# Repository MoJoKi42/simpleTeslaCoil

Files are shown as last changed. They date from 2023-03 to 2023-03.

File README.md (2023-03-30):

# simpleTeslaCoil
just a simple TeslaCoil (SSTC) with basic components

<ins>Few facts:</ins>
- 12-24V input voltage
- around 3-4A current maximum
- up to 550kHz frequency possible
- 100x100mm board

Picture of the finished board:
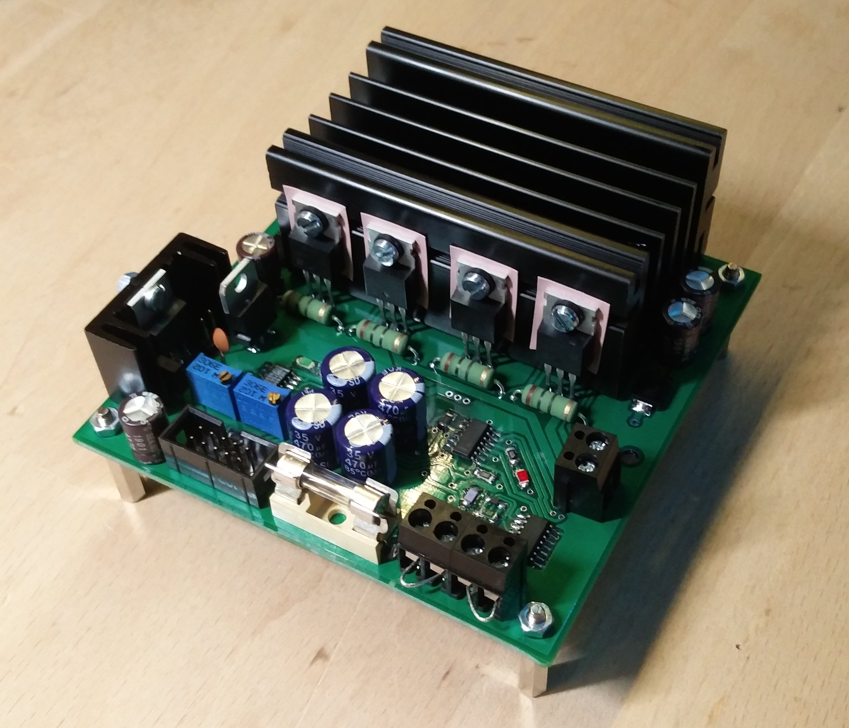
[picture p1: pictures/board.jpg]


And a picture of my final construction with coil and PSU:
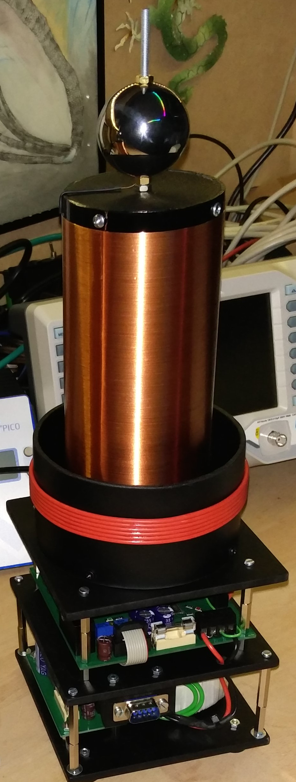
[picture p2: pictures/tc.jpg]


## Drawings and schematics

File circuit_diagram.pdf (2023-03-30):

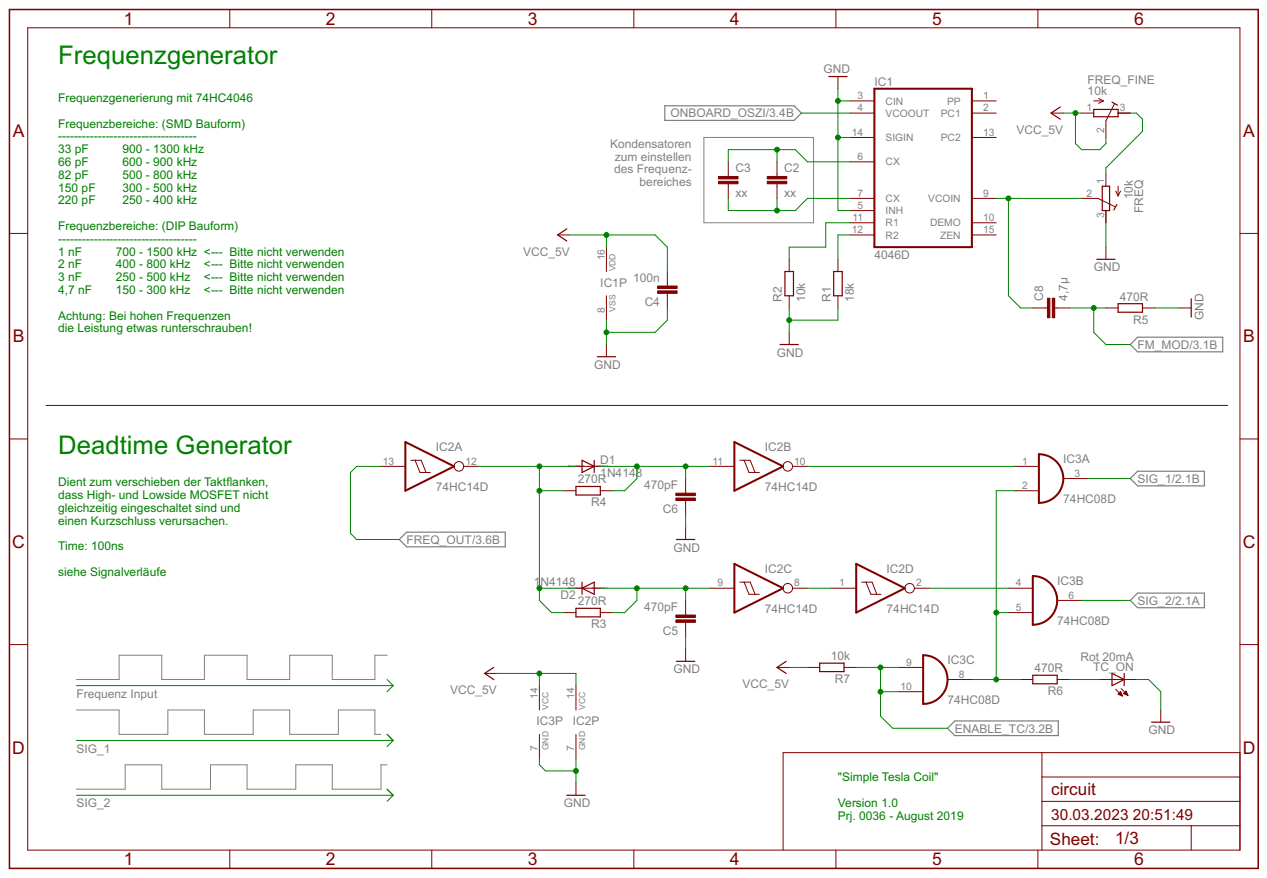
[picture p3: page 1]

die Leistung etwas runterschrauben!

Dient zum verschieben der Taktflanken, dass High- und Lowside MOSFET nicht

gleichzeitig eingeschaltet sind und
einen Kurzschluss verursachen. Time: 100ns

"Simple Tesla Coil" Version 1.0 Prj. 0036 - August 2019

Sheet: 1/3

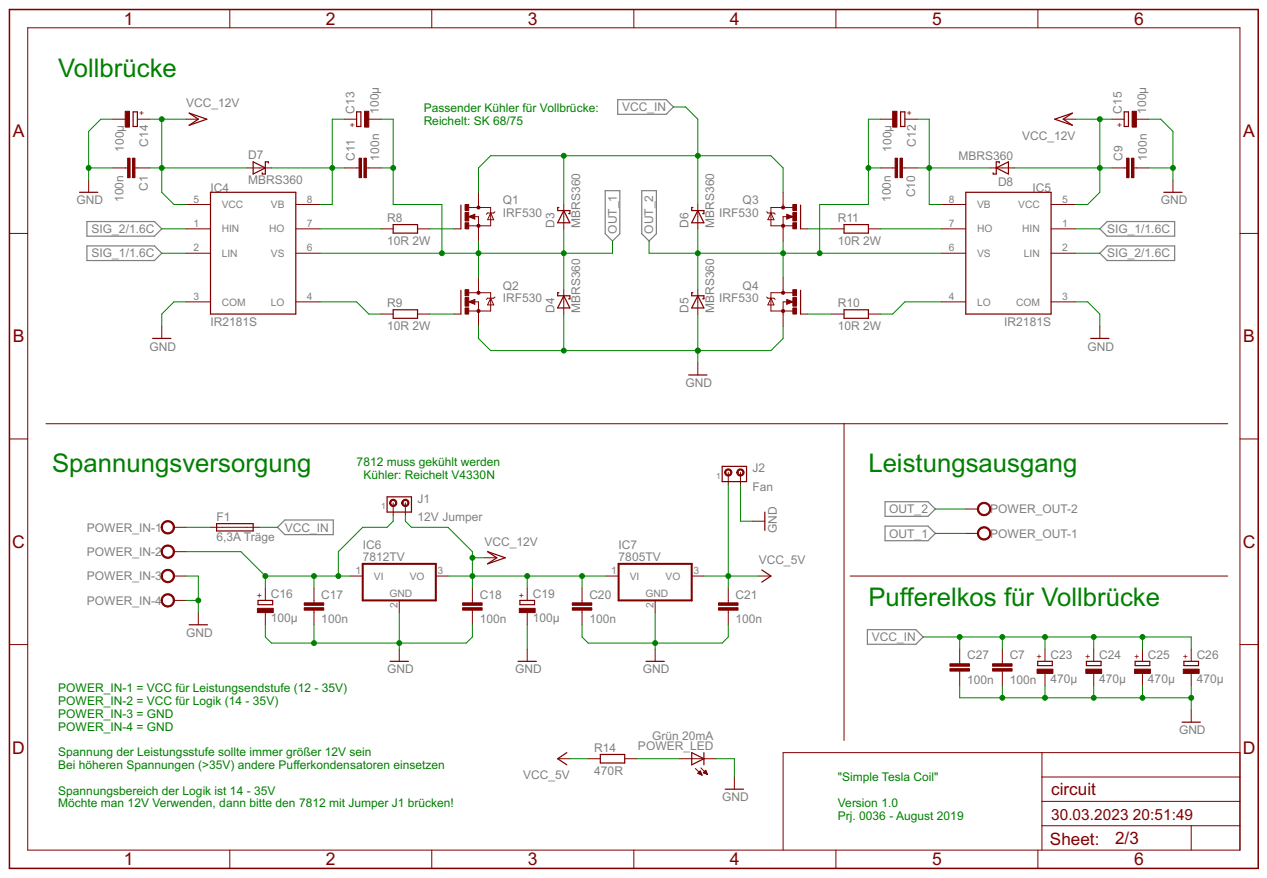
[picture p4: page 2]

Passender Kühler für Vollbrücke: Reichelt: SK 68/75

Spannung der Leistungsstufe sollte immer größer 12V sein Bei höheren Spannungen (>35V) andere Pufferkondensatoren einsetzen Spannungsbereich der Logik ist 14 - 35V

"Simple Tesla Coil" Version 1.0 Prj. 0036 - August 2019

Möchte man 12V Verwenden, dann bitte den 7812 mit Jumper J1 brücken!

Sheet: 2/3

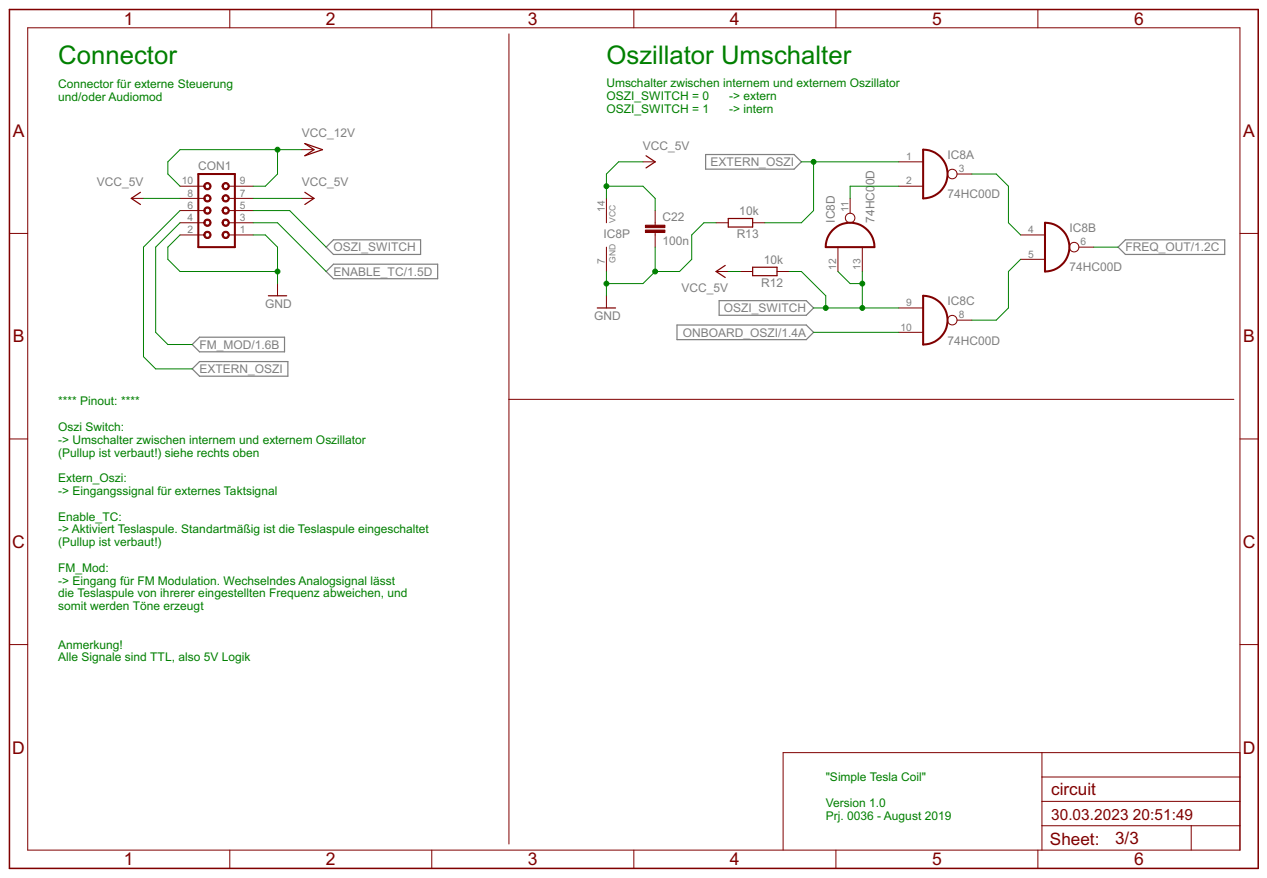
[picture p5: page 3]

Connector für externe Steuerung
und/oder Audiomod

**** Pinout: **** Oszi Switch: -> Umschalter zwischen internem und externem Oszillator

(Pullup ist verbaut!) siehe rechts oben Extern_Oszi: -> Eingangssignal für externes Taktsignal

Enable_TC: -> Aktiviert Teslaspule. Standartmäßig ist die Teslaspule eingeschaltet

FM_Mod: -> Eingang für FM Modulation. Wechselndes Analogsignal lässt

die Teslaspule von ihrerer eingestellten Frequenz abweichen, und
somit werden Töne erzeugt

Anmerkung!
Alle Signale sind TTL, also 5V Logik

"Simple Tesla Coil" Version 1.0 Prj. 0036 - August 2019

Sheet: 3/3

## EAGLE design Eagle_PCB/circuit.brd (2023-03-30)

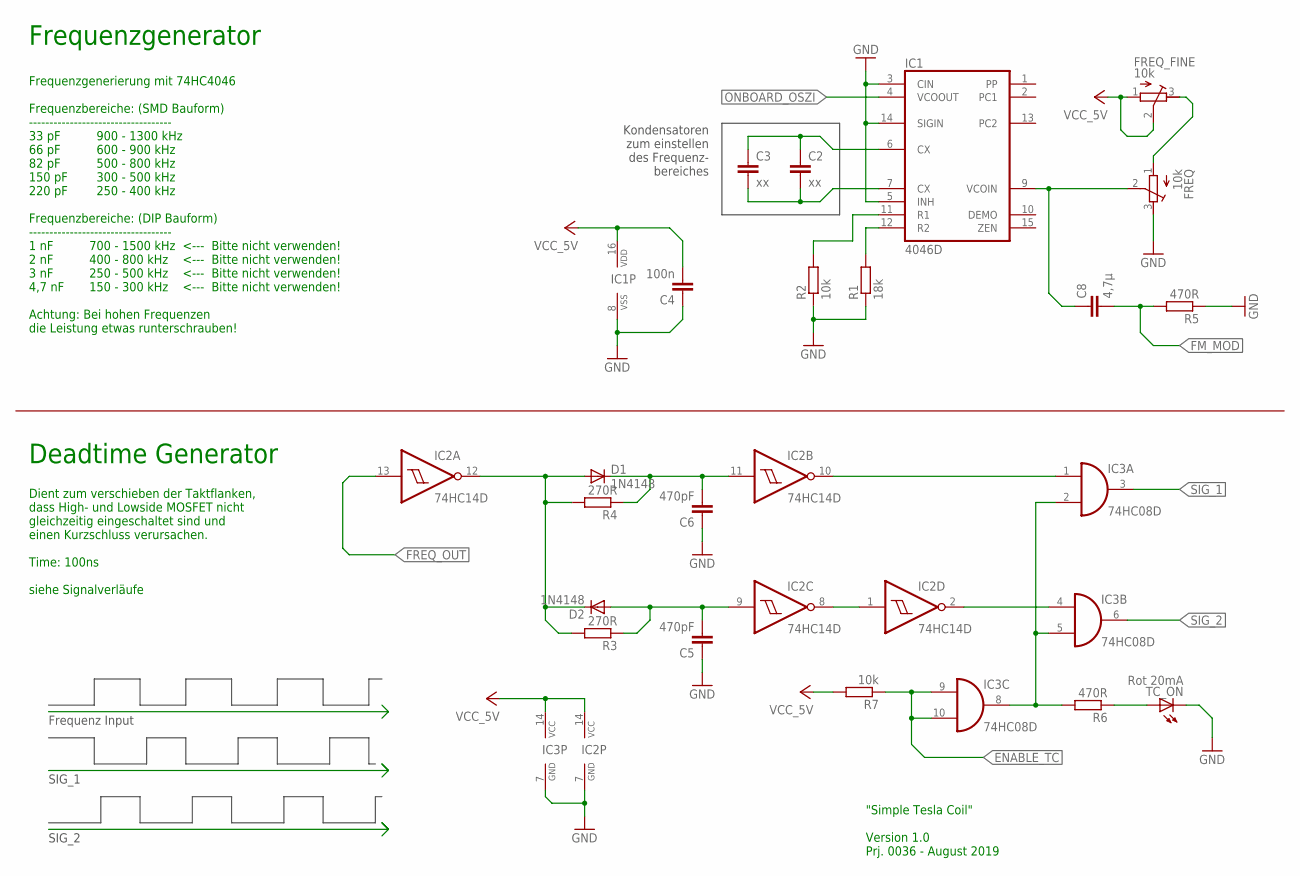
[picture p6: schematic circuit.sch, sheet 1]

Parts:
C2, C3: xx; C0805K
C4: 100n; C1206K
C5, C6: 470pF; C1206K
C8: 4,7µ; C1206K
D1, D2: 1N4148; SOD323-W
FREQ: 10k; RTRIM64W
FREQ_FINE: 10k; RTRIM64W
IC1: 4046D; SO16
IC2: 74HC14D; SO14
IC3: 74HC08D; SO14
R1: 18k; M1206
R2, R7: 10k; M1206
R3, R4: 270R; M1206
R5, R6: 470R; M1206
TC_ON: Rot 20mA; 1206

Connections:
ENABLE_TC: IC3.9 (I0), IC3.10 (I1), R7.1; also elsewhere on the board
ENABLE_TC2: IC3.2 (I1), IC3.5 (I1), IC3.8 (O), R6.2
FM_MOD: C8.2, R5.2; also elsewhere on the board
FREQ_OUT: IC2.13 (I); also elsewhere on the board
GND: C4.1, C5.1, C6.1, FREQ.3 (E), IC1.3 (CIN), IC1.5 (INH), IC1.8 (VSS), IC1.14 (SIGIN), IC2.7 (GND), IC3.7 (GND), R1.1, R2.1, R5.1, TC_ON.C; also elsewhere on the board
unnamed: C2.1, C3.1, IC1.6 (CX)
unnamed: C2.2, C3.2, IC1.7 (CX)
unnamed: C5.2, D2.A, IC2.9 (I), R3.1
unnamed: C8.1, FREQ.2 (S), IC1.9 (VCOIN)
unnamed: R6.1, TC_ON.A
unnamed: IC1.11 (R1), R2.2
unnamed: IC1.12 (R2), R1.2
unnamed: D1.A, D2.C, IC2.12 (O), R3.2, R4.2
unnamed: C6.2, D1.C, IC2.11 (I), R4.1
unnamed: IC2.1 (I), IC2.8 (O)
unnamed: IC2.2 (O), IC3.4 (I0)
unnamed: IC2.10 (O), IC3.1 (I0)
unnamed: FREQ.1 (A), FREQ_FINE.3 (E)
ONBOARD_OSZI: IC1.4 (VCOOUT); also elsewhere on the board
SIG_1: IC3.3 (O); also elsewhere on the board
SIG_2: IC3.6 (O); also elsewhere on the board
VCC: C4.2, FREQ_FINE.1 (A), FREQ_FINE.2 (S), IC1.16 (VDD), IC2.14 (VCC), IC3.14 (VCC), R7.2; also elsewhere on the board

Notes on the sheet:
Frequenzgenerator
Deadtime Generator
Kondensatoren zum einstellen des Frequenz- bereiches
Frequenz Input
SIG_1
SIG_2
Dient zum verschieben der Taktflanken, dass High- und Lowside MOSFET nicht gleichzeitig eingeschaltet sind und einen Kurzschluss verursachen. Time: 100ns siehe Signalverläufe
Frequenzgenerierung mit 74HC4046 Frequenzbereiche: (SMD Bauform) ----------------------------------- 33 pF 900 - 1300 kHz 66 pF 600 - 900 kHz 82 pF 500 - 800 kHz 150 pF 300 - 500 kHz 220 pF 250 - 400 kHz Frequenzbereiche: (DIP Bauform) ----------------------------------- 1 nF 700 - 1500 kHz <--- Bi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
"Simple Tesla Coil" Version 1.0 Prj. 0036 - August 2019

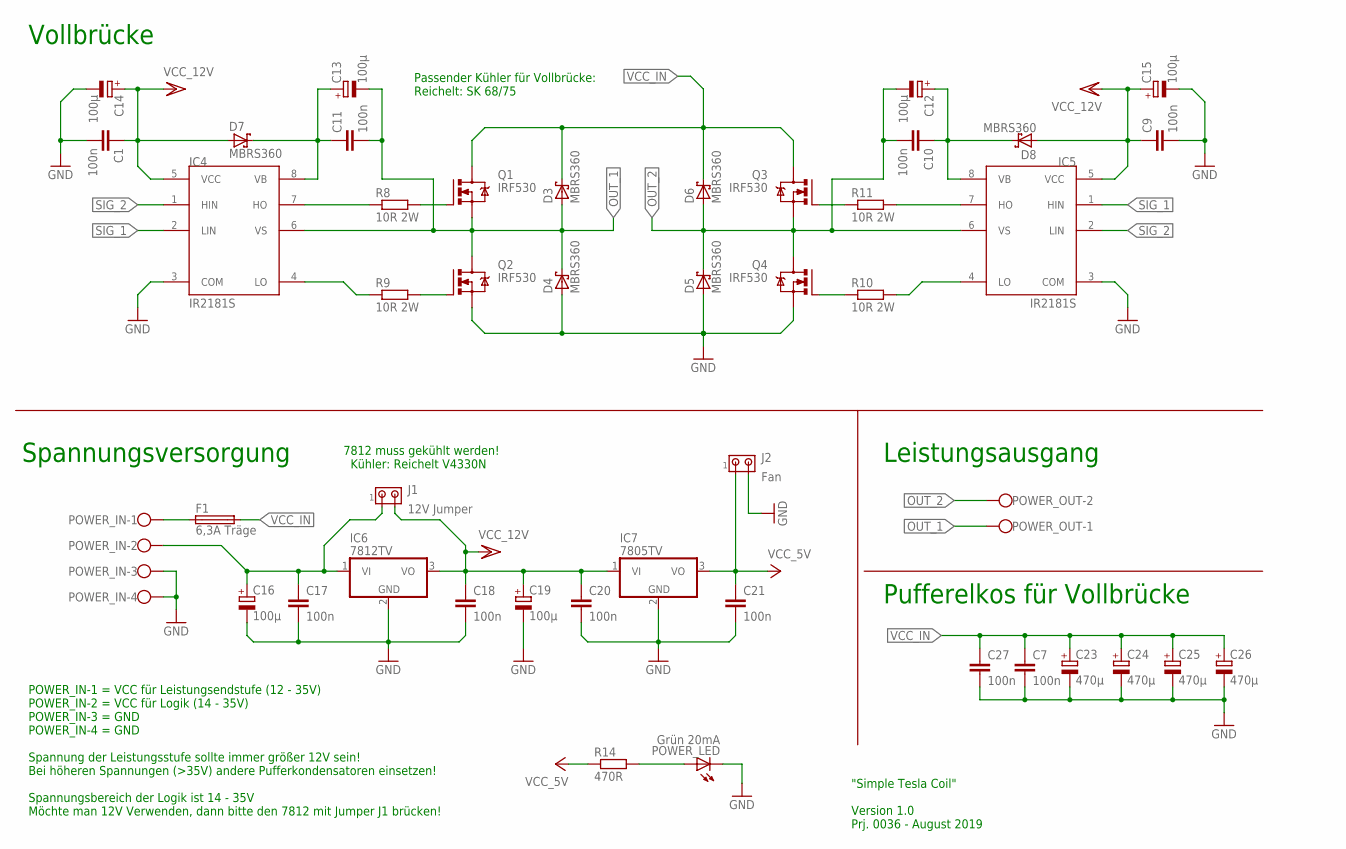
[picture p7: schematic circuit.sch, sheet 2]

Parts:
C1, C7, C9, C10, C11, C17, C18, C20, C21, C27: 100n; C1206K
C12, C13, C14, C15, C16, C19: 100µ; E2,5-7
C23, C24, C25, C26: 470µ; E5-10,5
D3, D4, D5, D6, D7, D8: MBRS360; SMC
F1: 6,3A Träge; SH22,5
IC4, IC5: IR2181S; SO08
IC6: 7812TV; TO220V
IC7: 7805TV; TO220V
J1: 12V Jumper; 10X02MTA
J2: Fan; 10X02MTA
POWER_IN: W237-4
POWER_LED: Grün 20mA; 1206
POWER_OUT: W237-102
Q1, Q2, Q3, Q4: IRF530; TO220BV
R8, R9, R10, R11: 10R 2W; 0411/15
R14: 470R; M1206

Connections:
GND: C1.2, C7.2, C9.2, C14.-, C15.-, C16.-, C17.2, C18.2, C19.-, C20.2, C21.2, C23.-, C24.-, C25.-, C26.-, C27.2, D4.A, D5.A, IC4.3 (COM), IC5.3 (COM), IC6.2 (GND), IC7.2 (GND), J2.2, POWER_IN.3, POWER_IN.4, POWER_LED.C, Q2.S, Q4.S; also elsewhere on the board
unnamed: IC4.7 (HO), R8.1
unnamed: IC4.4 (LO), R9.1
unnamed: IC5.7 (HO), R11.2
unnamed: IC5.4 (LO), R10.2
unnamed: F1.1, POWER_IN.1
unnamed: Q3.G, R11.1
unnamed: Q4.G, R10.1
unnamed: Q2.G, R9.2
unnamed: C16.+, C17.1, IC6.1 (VI), J1.1, POWER_IN.2
unnamed: POWER_LED.A, R14.2
unnamed: Q1.G, R8.2
OUT_1: C11.2, C13.-, D3.A, D4.C, IC4.6 (VS), POWER_OUT.1, Q1.S, Q2.D
OUT_2: C10.2, C12.-, D5.C, D6.A, IC5.6 (VS), POWER_OUT.2, Q3.S, Q4.D
SIG_1: IC4.2 (LIN), IC5.1 (HIN); also elsewhere on the board
SIG_2: IC4.1 (HIN), IC5.2 (LIN); also elsewhere on the board
VB: C11.1, C13.+, D7.C, IC4.8 (VB)
VB_2: C10.1, C12.+, D8.C, IC5.8 (VB)
VCC: C21.1, IC7.3 (VO), J2.1, R14.1; also elsewhere on the board
VCC/2: C1.1, C9.1, C14.+, C15.+, C18.1, C19.+, C20.1, D7.A, D8.A, IC4.5 (VCC), IC5.5 (VCC), IC6.3 (VO), IC7.1 (VI), J1.2; also elsewhere on the board
VCC_IN: C7.1, C23.+, C24.+, C25.+, C26.+, C27.1, D3.C, D6.C, F1.2, Q1.D, Q3.D

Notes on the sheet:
Vollbrücke
Passender Kühler für Vollbrücke: Reichelt: SK 68/75
POWER_IN-1 = VCC für Leistungsendstufe (12 - 35V) POWER_IN-2 = VCC für Logik (14 - 35V) POWER_IN-3 = GND POWER_IN-4 = GND Spannung der Leistungsstufe sollte immer größer 12V sein! Bei höheren Spannungen (>35V) andere Pufferkondensatoren einsetzen! Spannungsbereich der Logik ist 14 - 35V Möchte man 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
7812 muss gekühlt werden! Kühler: Reichelt V4330N
Spannungsversorgung
Leistungsausgang
Pufferelkos für Vollbrücke
"Simple Tesla Coil" Version 1.0 Prj. 0036 - August 2019

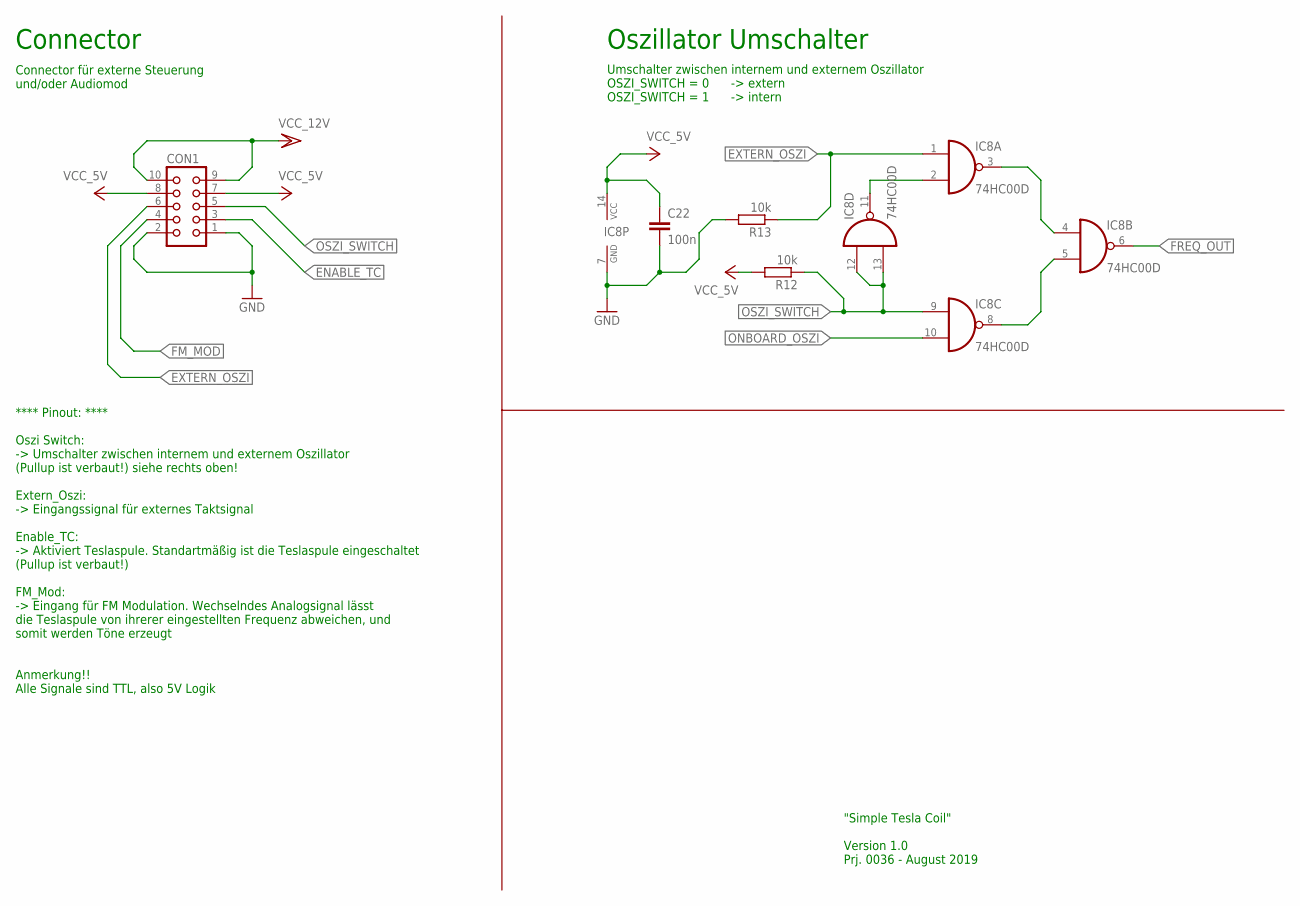
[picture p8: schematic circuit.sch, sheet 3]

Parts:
C22: 100n; C1206K
CON1: CON10
IC8: 74HC00D; SO14
R12, R13: 10k; M1206

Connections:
ENABLE_TC: CON1.3; also elsewhere on the board
EXTERN_OSZI: CON1.6, IC8.1 (I0), R13.1
FM_MOD: CON1.4; also elsewhere on the board
FREQ_OUT: IC8.6 (O); also elsewhere on the board
GND: C22.2, CON1.1, CON1.2, IC8.7 (GND), R13.2; also elsewhere on the board
unnamed: IC8.2 (I1), IC8.11 (O)
unnamed: IC8.3 (O), IC8.4 (I0)
unnamed: IC8.5 (I1), IC8.8 (O)
ONBOARD_OSZI: IC8.10 (I1); also elsewhere on the board
OSZI_SWITCH: CON1.5, IC8.9 (I0), IC8.12 (I0), IC8.13 (I1), R12.1
VCC: C22.1, CON1.7, CON1.8, IC8.14 (VCC), R12.2; also elsewhere on the board
VCC/2: CON1.9, CON1.10; also elsewhere on the board

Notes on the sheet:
Connector
Connector für externe Steuerung und/oder Audiomod
Oszillator Umschalter
Umschalter zwischen internem und externem Oszillator OSZI_SWITCH = 0 -> extern OSZI_SWITCH = 1 -> intern
**** Pinout: **** Oszi Switch: -> Umschalter zwischen internem und externem Oszillator (Pullup ist verbaut!) siehe rechts oben! Extern_Oszi: -> Eingangssignal für externes Taktsignal Enable_TC: -> Aktiviert Teslaspule. Standartmäßig ist die Teslaspule eingeschaltet (Pullup ist verbaut!) FM_Mod: -> 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
"Simple Tesla Coil" Version 1.0 Prj. 0036 - August 2019

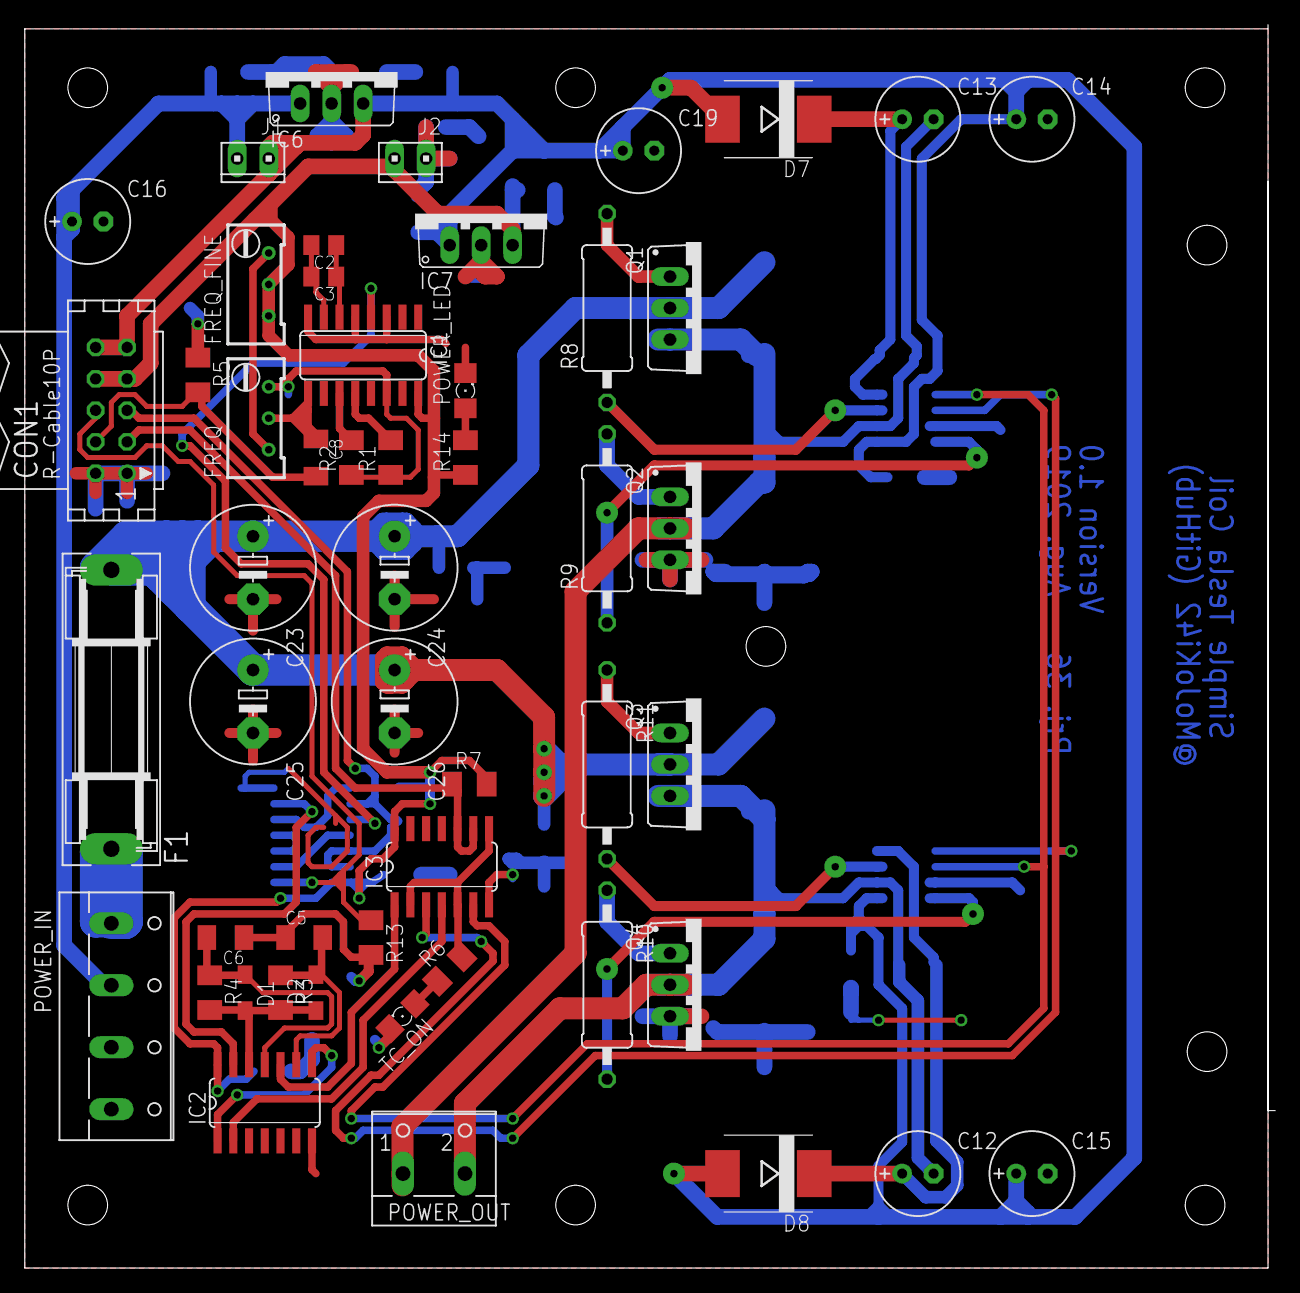
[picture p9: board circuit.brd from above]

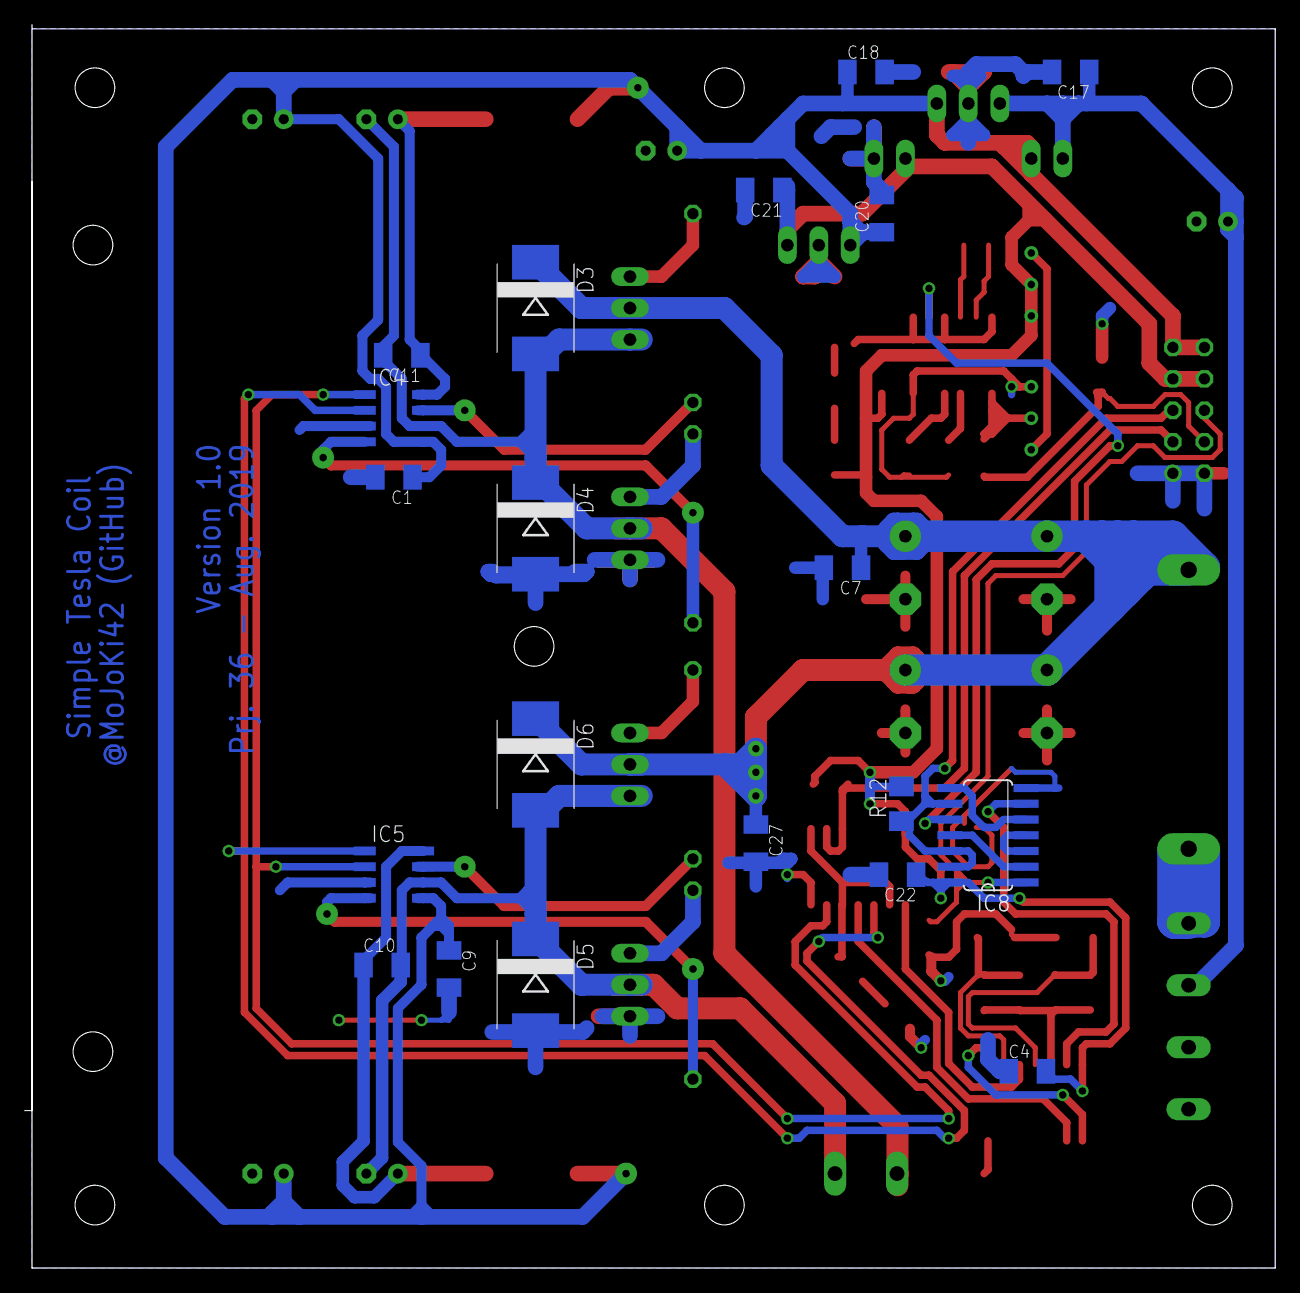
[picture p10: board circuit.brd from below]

Board: 2 copper layers, 100.9 x 100.3 mm, 71 parts (20 on the bottom side), 44 nets.
